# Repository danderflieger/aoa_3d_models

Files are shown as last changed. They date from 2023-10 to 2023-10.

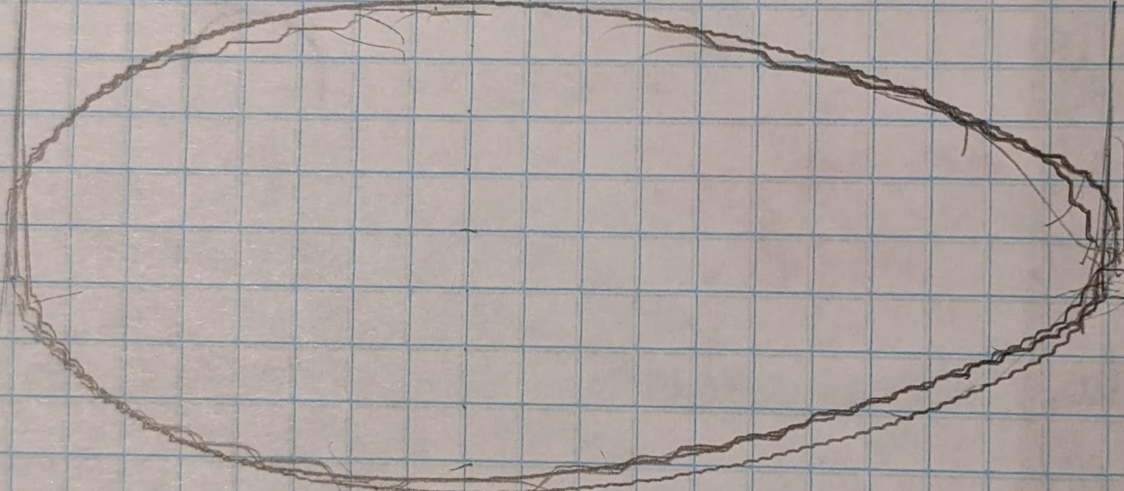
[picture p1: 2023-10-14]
Solidworks_Files/PXL_20221007_203024921.MP.jpg

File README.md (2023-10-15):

# Disclaimer:
By using this Angle of Attack Sensor (sensor) and/or Angle of Attack Indicator software (indicator), you agree with the following:
- you understand and agree that, while the sensor and indicator can contribute to better situational awareness in the cockpit, they are NOT designed or certified to be used as/by a primary flight instrument
- you understand and agree that the data produced by the sensor and/or the indicator will NOT be used as/by a primary flight instrument
- you understand and agree that the pilot in command is SOLELY responsible for the safe outcome of every flight
- the pilot in command accepts FULL responsibility for any accident, harm, death, and/or loss that occurs while using the sensor and/or indicator
- the pilot in command has briefed all passengers and all passengers agree to the same
- the pilot in command (and each passenger) agrees to NOT hold the designer and/or builder of the sensor and/or indicator responsible for any accident, harm, death and/or loss that occurs while using the sensor and/or indicator, unless the designer and/or builder is the designated pilot in command during the flight

# AoA 3D Models (Solidworks, 3MF, and STL)
This is a repository for 3D printable parts (Solidworks parts &amp; assemblies as well as STL and 3MF files). You can edit the Solidworks files, if you like. And if you just want to print the parts, 
just load the STL/3MF files into your 3D Slicer software. I like Ultimaker Cura (https://ultimaker.com/software/ultimaker-cura), but any slicer software that can interpret STL or 3MF files should work.

The repository is split up into four directories: 
### Solidworks_Files
Contains files that can be edited in Solidworks (SLDPRT and SLDASM files)

### Solidworks_Drawing_Files
Drawings that can be used as templates for holes and to ensure you're bending an aluminum plate in the right place (C152 mount).

### 3MF_Files
As the name suggests, this directory contains 3MF files, which can be used by a slicer program to tell a 3D printer how to print the object.

### STL_Files. 
As the name suggests, this directory contains STL files, which can be used by a slicer program to tell a 3D printer how to print the object.

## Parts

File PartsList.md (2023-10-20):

# Parts List
## Electronics 
### 1x Arduino Nano 33 BLE OR Arduino Nano 33 IoT OR Arduino Nano RP2040 (all three models have been tested)
 - https://store-usa.arduino.cc/products/arduino-nano-33-ble
 - https://store-usa.arduino.cc/products/arduino-nano-33-iot
 - https://store-usa.arduino.cc/collections/nano-family/products/arduino-nano-rp2040-connect

### 1x AS5600 Rotary Encoder with Magnet
- https://www.amazon.com/Magnetic-Encoder-Induction-Measurement-Precision/dp/B094F8H591/?th=1

### 1x 12mm Latching Push Button Switch
- https://www.amazon.com/dp/B0BWJHSLVK

### 1x Battery Holder w/9V Snap Leads
- https://www.amazon.com/dp/B01MAXT00Q1

### 1x 3mm LED (3-3.3V)
- https://www.amazon.com/dp/B01C3W6NSK

### 1x Stranded, Tinned Copper Wire Kit 22AWG
- https://www.amazon.com/dp/B0881HCN37

### Adhesive Heat Shrink Tube (1/8")
- https://www.amazon.com/dp/B0BC1GV6GM/

## Mechanical/Hardware
### 1x 5mm Bore Rigid Coupling
- https://www.amazon.com/gp/product/B07P6X9GSQ/?th=1

### 1x 5mm Stainless Steel Round Rod (stainless is not magnetic)
- https://www.amazon.com/gp/product/B082ZPC5YF

### 2x 5mm Inner Diameter x 11mm Outer Diameter x 4mm Bore Ball Bearing
- https://www.amazon.com/gp/product/B082PSBLVR 

### 1x 5mm Inner Diameter Rigid Flange Coupler
- https://www.amazon.com/gp/product/B07PFW6GKL

### 1x Square Carbon Fiber Tubes 4x4x3x200mm Inner Round
- https://www.amazon.com/dp/B096G6BJHY

### Various sizes of M3 Screws
- https://www.amazon.com/gp/product/B08H24W42K

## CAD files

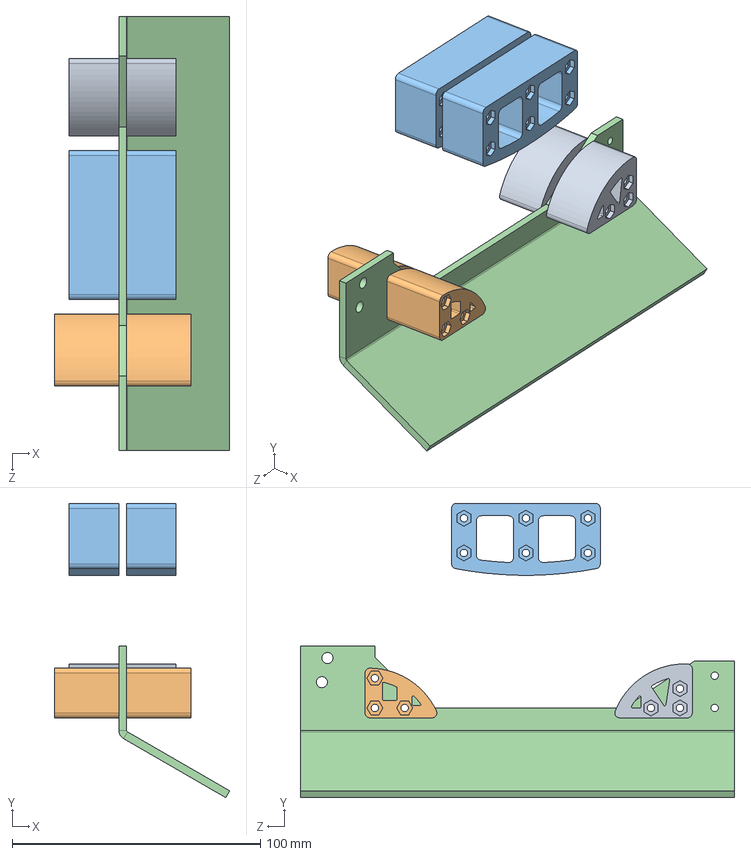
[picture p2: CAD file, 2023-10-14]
Solidworks_Files/Mount_C152_Assembly.SLDASM
70.7 x 118.7 x 175.0 mm
Mount_C152_Aluminum_Bottom_Center_Plate
Mount_C152_Plastic_Top x 2
Mount_C152_Plastic_Bottom Front x 2
Mount_C152_Plastic_Bottom_Back x 2

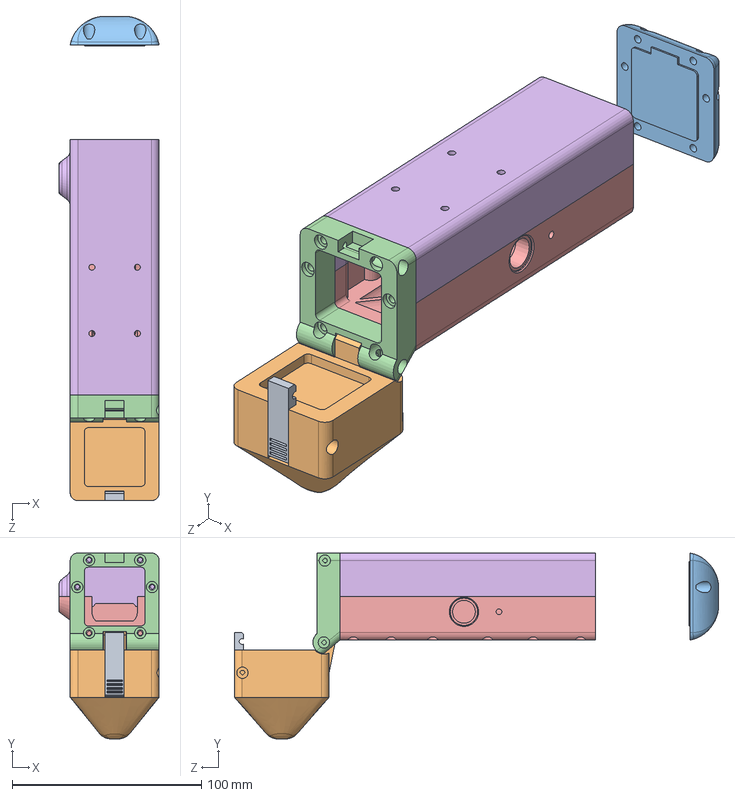
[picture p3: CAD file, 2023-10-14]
Solidworks_Files/AoA_Assembly_V5a.SLDASM
53.0 x 98.2 x 255.8 mm
BatteryBodyTop_v5a
BatteryBodyBottom_v5a
BatteryCoverLockRing_v5
FrontCap_V5a
RearCap_V5a
BatteryLock_v5

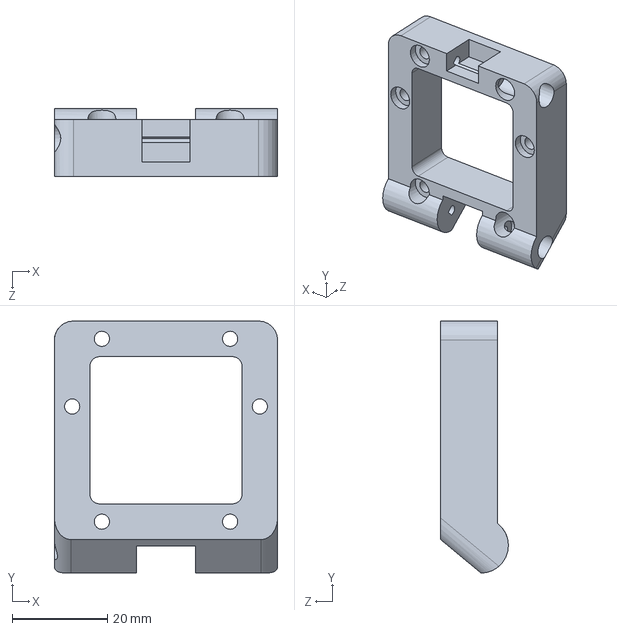
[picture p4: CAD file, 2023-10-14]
Solidworks_Files/BatteryCoverLockRing_v5.SLDPRT
47.0 x 53.0 x 14.3 mm

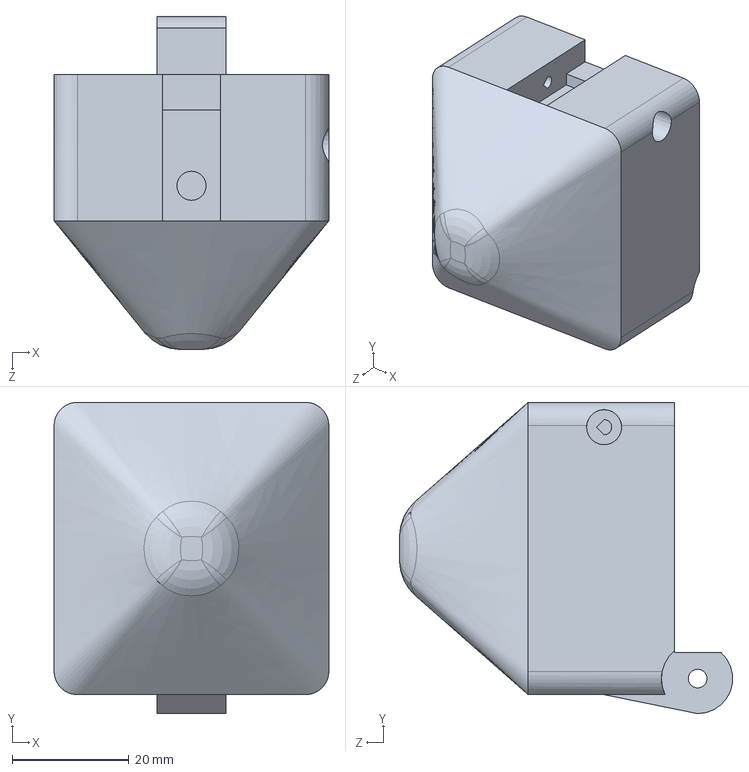
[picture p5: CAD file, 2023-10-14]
Solidworks_Files/RearCap_V5a.SLDPRT
47.0 x 53.2 x 57.0 mm

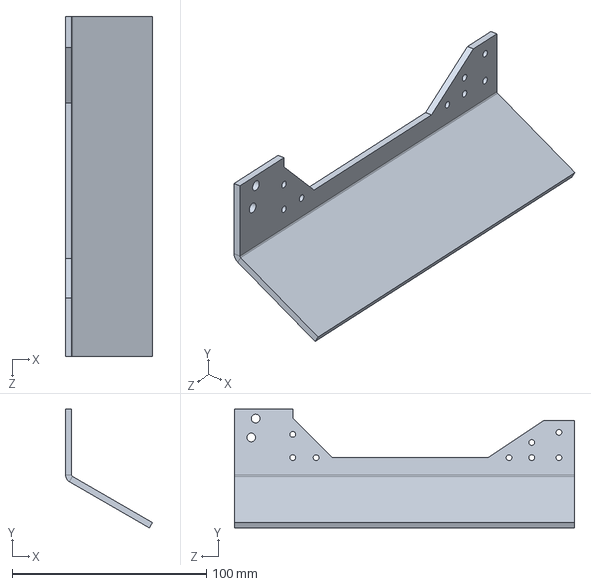
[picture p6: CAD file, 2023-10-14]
Solidworks_Files/Mount_C152_Aluminum_Bottom_Center_Plate.SLDPRT
44.7 x 61.2 x 175.0 mm

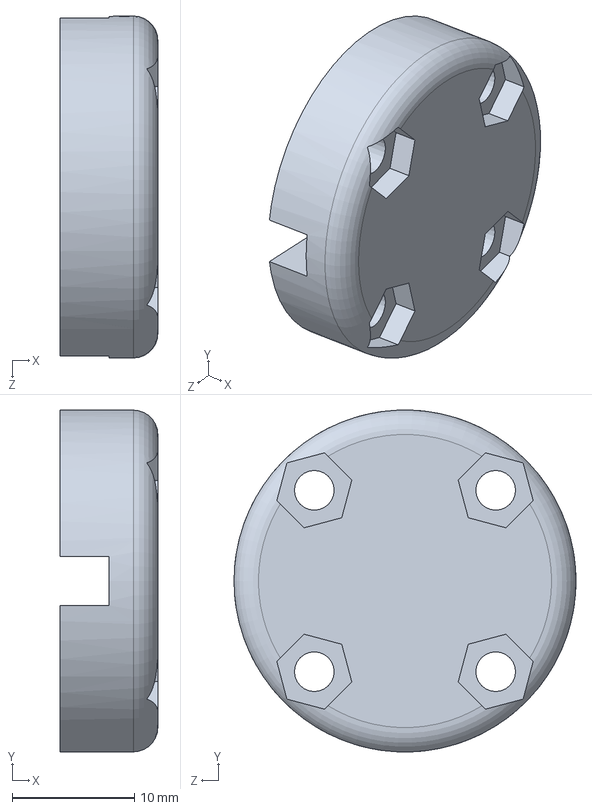
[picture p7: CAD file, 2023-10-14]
Solidworks_Files/WindWedgeHub_v5.SLDPRT
8.00 x 28.0 x 28.0 mm

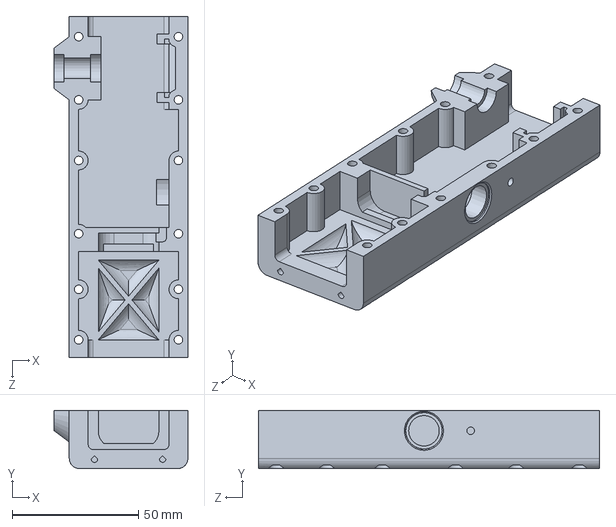
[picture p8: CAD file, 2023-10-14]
Solidworks_Files/BatteryBodyBottom_v5a.SLDPRT
53.0 x 23.0 x 135.0 mm

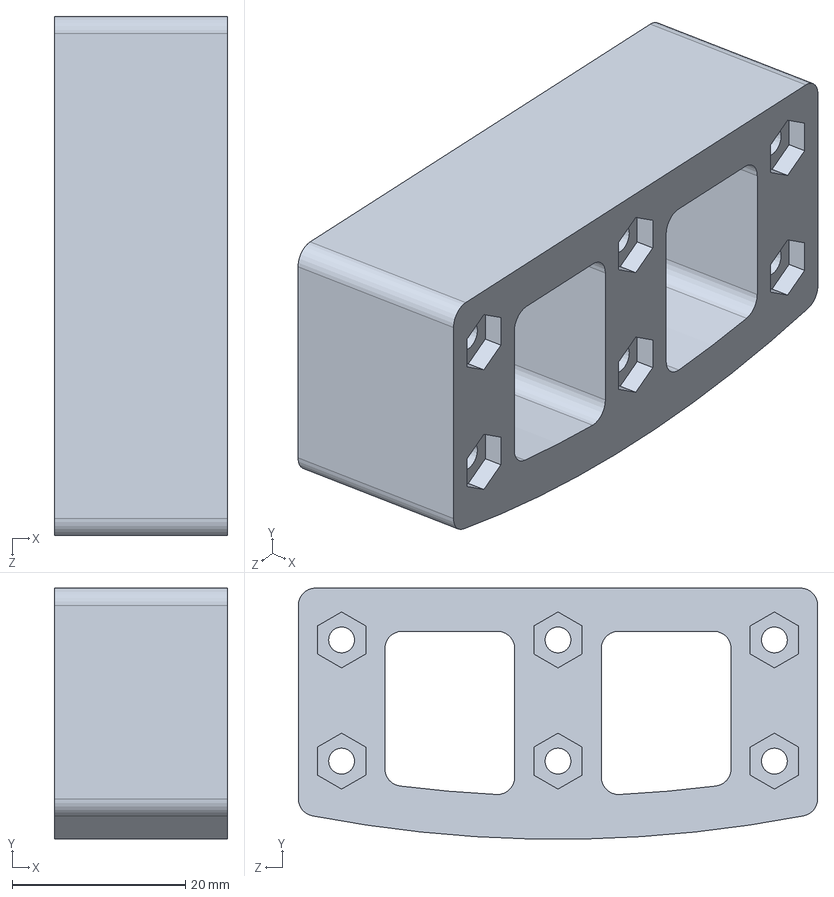
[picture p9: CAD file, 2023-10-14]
Solidworks_Files/Mount_C152_Plastic_Top.SLDPRT
20.0 x 29.0 x 60.0 mm

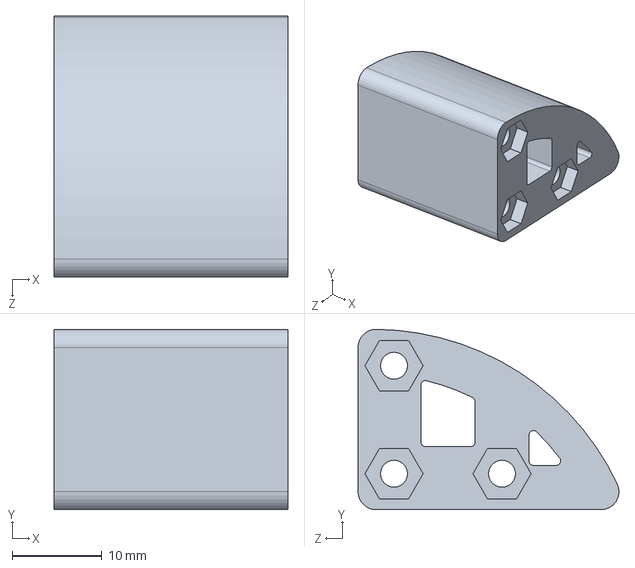
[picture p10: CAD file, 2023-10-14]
Solidworks_Files/Mount_C152_Plastic_Bottom Front.SLDPRT
26.0 x 20.0 x 29.0 mm

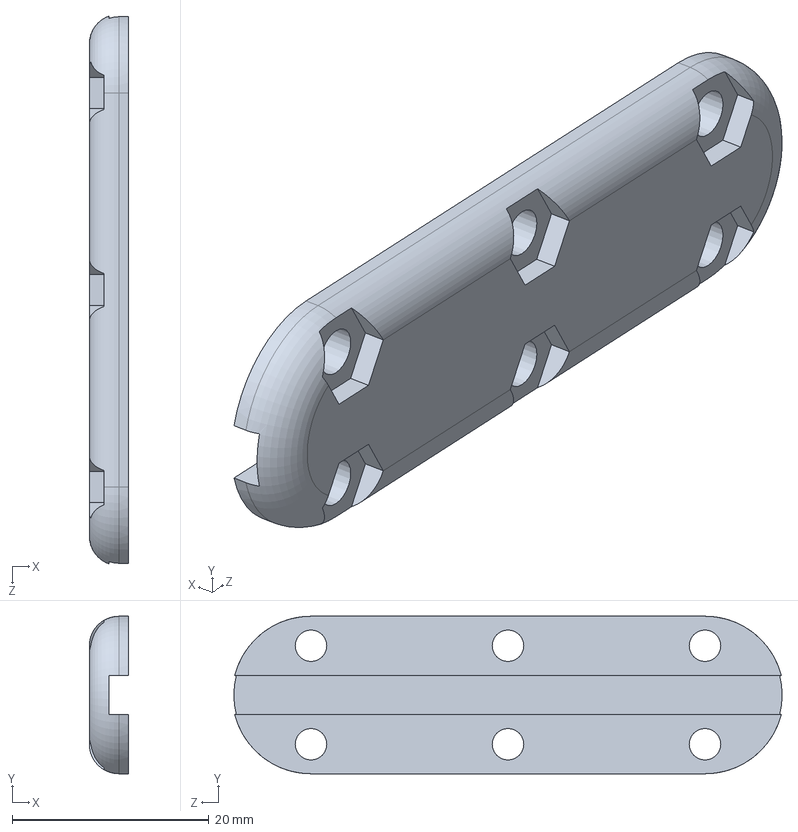
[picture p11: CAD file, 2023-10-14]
Solidworks_Files/WindWedgeBack_v2.SLDPRT
4.00 x 16.0 x 55.6 mm

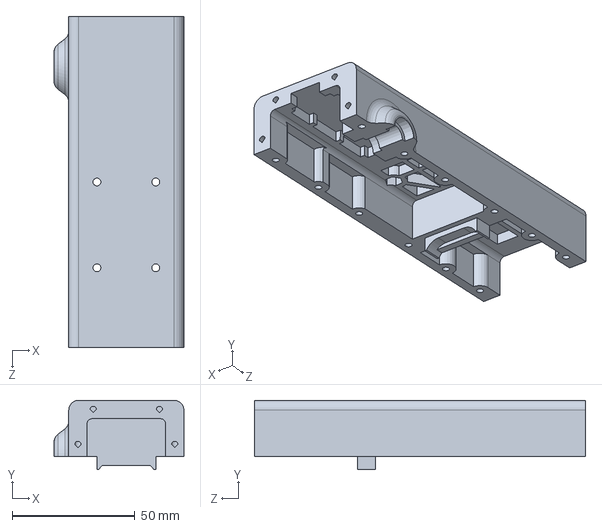
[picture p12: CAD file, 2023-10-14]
Solidworks_Files/BatteryBodyTop_v5a.SLDPRT
53.0 x 28.3 x 135.0 mm

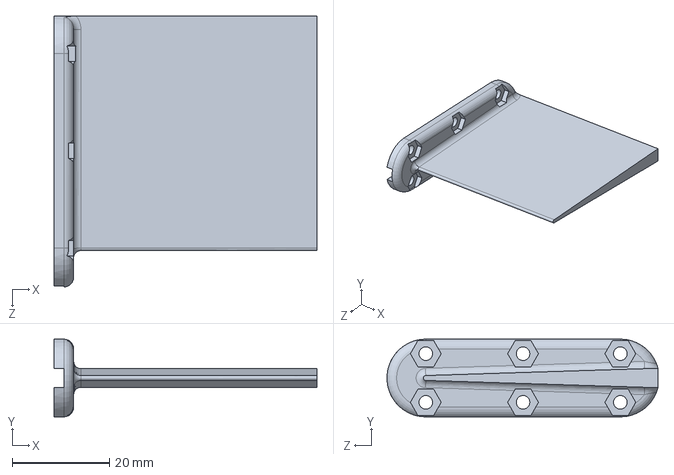
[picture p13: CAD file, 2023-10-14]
Solidworks_Files/WindWedge_v2.SLDPRT
54.0 x 16.0 x 55.7 mm

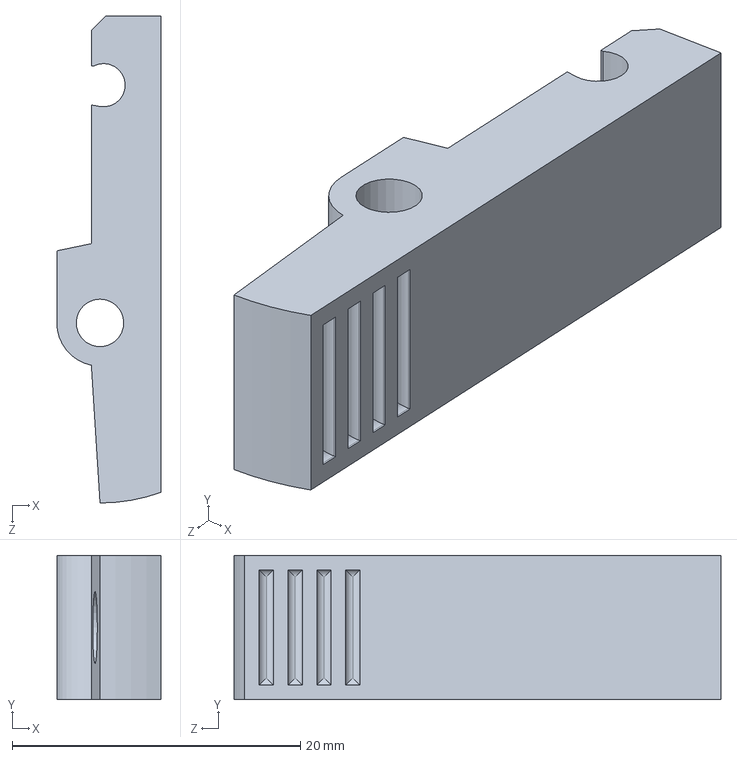
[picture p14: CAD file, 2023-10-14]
Solidworks_Files/BatteryLock_v5.SLDPRT
7.25 x 10.0 x 33.8 mm

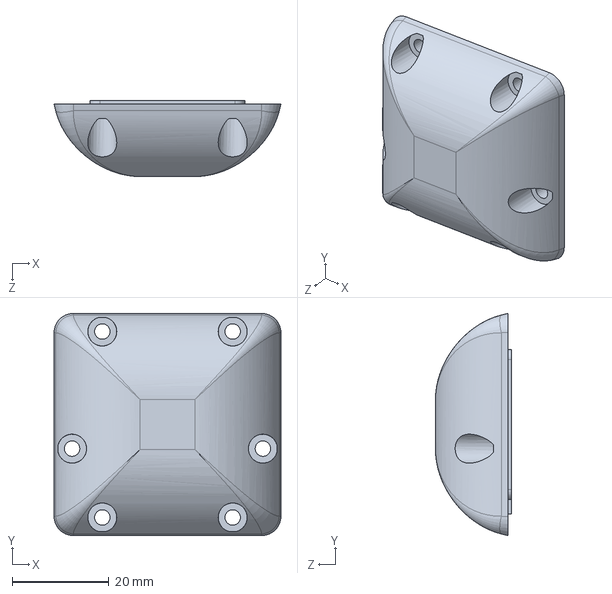
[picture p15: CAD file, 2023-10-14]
Solidworks_Files/FrontCap_V5a.SLDPRT
47.0 x 46.0 x 15.8 mm

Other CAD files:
Solidworks_Files/Mount_C152_Plastic_Bottom_Back.SLDPRT
Solidworks_Files/WindWedgeCounterWeight_v2.SLDPRT
Solidworks_Files/Mount_C152_Aluminum_Bottom_Plate.SLDPRT
Solidworks_Files/1mmSpacer_v5.SLDPRT
3MF_Files/1mmSpacer_v5.3MF
3MF_Files/BatteryBodyBottom_v5a.3MF
3MF_Files/BatteryBodyTop_v5a.3MF
3MF_Files/BatteryCoverLockRing_v5.3MF
3MF_Files/BatteryLock_v5.3MF
3MF_Files/FrontCap_V5a.3MF
3MF_Files/Mount_C152_Plastic_Bottom Front.3MF
3MF_Files/Mount_C152_Plastic_Bottom_Back.3MF
3MF_Files/Mount_C152_Plastic_Top.3MF
3MF_Files/RearCap_V5a.3MF
3MF_Files/WindWedgeBack_v2.3MF
3MF_Files/WindWedgeCounterWeight_v2.3MF
3MF_Files/WindWedgeHub_v5.3MF
3MF_Files/WindWedge_v2.3MF
STL_Files/1mmSpacer_v5.STL
STL_Files/BatteryBodyBottom_v5a.STL
STL_Files/BatteryBodyTop_v5a.STL
STL_Files/BatteryCoverLockRing_v5.STL
STL_Files/BatteryLock_v5.STL
STL_Files/FrontCap_V5a.STL
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

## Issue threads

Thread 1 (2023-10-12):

Can’t see solidworks file or 3mf files

kieranshanley, 2023-10-12:
Hi Dan,

saw your video and thought I’d checkout your aoa project. I’ve can only see the readme file in the repo. Would you be able to check if you have committed all the files ? Cheers Kieran

danderflieger, 2023-10-12:
Hi Kieran. After a few test flights of my updated version, I found that the device was making inconsistent readings. I believe the mount was flexing up as I increased my angle of attack. So I made a complete redesign of the entire sensor (smaller) and designed a mount that uses a 1/8" aluminum plate to ensure the mount doesn't flex.

Then I purchased my airplane kit and never actually test flew the new design, so I don't feel comfortable making it available to the general public. If you're interested in building one and testing it for me, I can probably make the design available to you.

I do have a flight planned for tomorrow evening and I suppose I can bring my new prototype to see if it works better than the previous one.

danderflieger, 2023-10-14:
I brought the latest version with me on my flight last night. It worked much better than the previous one. In the next few days, I'll go ahead and post the Solidworks/STL/3MF files for the current version.

kieranshanley, 2023-10-14:
That’s exciting news. I think I would like to build a test rig and see if I
can help test it for you.

Cheers

Kieran

On Sun, 15 Oct 2023 at 5:07 am, Dan Der Flieger ***@***.***>
wrote:

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

danderflieger, 2023-10-15:
The files have been committed and pushed. I also added a PartsList.md file to the root of the repository that should include all of the parts you need to assemble it (along with the printed parts). Hopefully I didn't forget anything. :)

Dan

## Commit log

2023-10-14 Created STL and 3MF files. Organized files in four directories: Solidworks_Files, Solidworks_Drawing_Files, 3MF_Files, STL_Files.
    [1mmSpacer_v5.3MF, 1mmSpacer_v5.SLDPRT, 1mmSpacer_v5.STL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]
2026-03-27 Removed 1mmSpacer file and added correct BearingSpacer file (5mm inside diameter)
